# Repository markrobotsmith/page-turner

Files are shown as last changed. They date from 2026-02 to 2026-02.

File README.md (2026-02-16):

# Page Turner

A bluetooth page turning device for musicians. Allows a user to turn pages on a tablet or other bluetooth device. Acts as a bluetooth keyboard and sends left/right arrow key presses.

- **Under $50** in parts
- Simple durable print design with minimal moving parts and assembly. Utilizes compliance as a spring.

## Parts List

- 1× printed enclosure (Polymaker PLA PRO — nearly any material will work)
- 2× keyboard keyswitches (any kind will work; leftover Gateron Yellows were used here) — [Gateron KS-3 Milky Pro](https://www.gateron.co/products/gateron-ks-3-milky-pro-switch-set?variant=41926847463513)
- 1× lithium polymer battery 3.3V 1400mAh — [Amazon](https://www.amazon.com/dp/B095W4HS75) (JST will be removed; polarity does not matter)
- 1× Seeed Studio nRF52840 microcontroller board — [Seeed XIAO BLE nRF52840](https://www.seeedstudio.com/Seeed-XIAO-BLE-nRF52840-p-5201.html)
- 8″×0.5″ adhesive-backed rubber (optional, for feet) — [Amazon](https://www.amazon.com/dp/B0CS2PT17T)

## Assembly

1. Install keyswitches by lifting each pedal and inserting the switch into the hole. Switch should seat so that connectors are accessible from the access compartment.
2. Cut the JST connector off of the battery. **Clip one wire at a time** to prevent shorts.
3. Solder the battery to the pads on the bottom of the nRF52840 board according to the wiring diagram.
4. Insert the nRF52840 and battery. Use hot glue to secure the board from sliding when using the USB-C port. Use a dot of glue behind the battery to secure it.
5. Cut 4 lengths of wire and solder the keyswitches to the inputs of the board according to the wiring diagram.
6. Plug the board into a computer and follow the [board configuration process](https://wiki.seeedstudio.com/XIAO_BLE/) from Seeed Studio, then upload the Arduino sketch.
7. Open Bluetooth settings on your device and pair to **PageTurner** as with any other Bluetooth device.
8. Turn pages hands-free!

## Battery

The nRF52840 has built-in battery charging. Simply charge via the USB-C port. Auto-sleep puts the device into low-power mode to preserve battery life.

## Quick Reference

| Action | How |
|---|-----|
| **Wake** | Press any button |
| **Next page** | Press → button (green flash) |
| **Previous page** | Press ← button (green flash) |
| **Reset pairing** | Hold → for 5 seconds (10 blue blinks = confirmed) |
| **Check battery** | Bluetooth settings on your device |
| **Auto-sleep** | After 30 min inactivity (yellow warning at 25 min) |

### LED Quick Reference

| Color | Pattern | Meaning |
| :---- | :--- | :--- |
| Blue | 2 blinks | Powered on |
| Green | Slow breath | Connected |
| Green | Quick flash | Success |
| Red | Quick flash | Not connected |
| Yellow | 3 blinks | Inactivity warning |
| Red | 3 slow blinks | Going to sleep |
| Blue | 10 rapid blinks | Pairing reset |

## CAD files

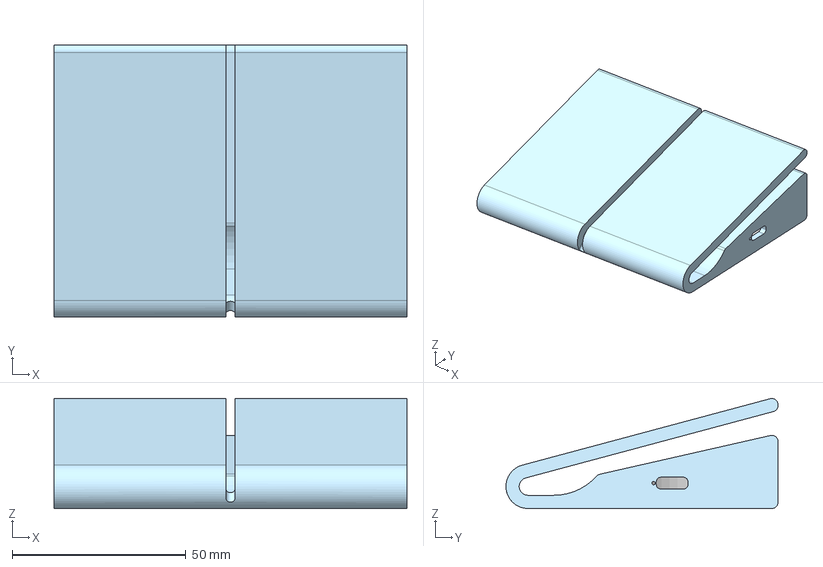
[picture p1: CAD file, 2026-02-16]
Page Turner v3.step
101.6 x 78.3 x 31.7 mm

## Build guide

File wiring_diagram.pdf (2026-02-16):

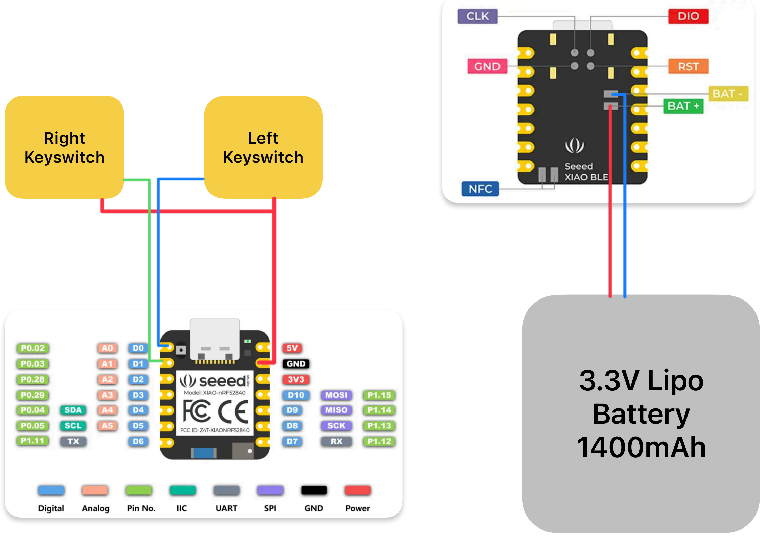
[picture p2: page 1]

# 3.3V Lipo Battery 1400mAh

Right
Keyswitch

Left
Keyswitch

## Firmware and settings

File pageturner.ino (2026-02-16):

#include <bluefruit.h>

// --- Config ---
#define PIN_BTN_NEXT    0  // D0
#define PIN_BTN_PREV    1  // D1

// XIAO nRF52840 specific internal pins for battery
#define PIN_VBAT        32 // P0.31 (AIN7) - Battery voltage sense
#define PIN_VBAT_ENABLE 14 // P0.14 - LOW to enable battery reading
#define PIN_HICHG       22 // P0.17 - Charge current setting (LOW=100mA, HIGH=50mA)
#define PIN_CHG         23 // P0.13 - Charge indicator (LOW=charging, HIGH=not charging)

// Auto-sleep timeout (1/2 hour = 3600000 ms)
#define INACTIVITY_TIMEOUT_MS 1800000UL  // 30min
//#define INACTIVITY_TIMEOUT_MS 60000UL  // 1 minute for testing

// Battery update interval (every 60 seconds)
#define BATTERY_UPDATE_INTERVAL 60000UL

// Warning time before auto-sleep (5 minutes before timeout)
#define WARNING_TIME_BEFORE_SLEEP 300000UL  // 5 minutes

BLEHidAdafruit blehid;
BLEBas blebas; // Battery Service
BLEDis bledis;

// Track last activity time
unsigned long lastActivityTime = 0;
unsigned long lastBatteryUpdate = 0;
bool warningShown = false;

void setup() {
  // 1. Setup Hardware
  pinMode(PIN_BTN_NEXT, INPUT_PULLUP);
  pinMode(PIN_BTN_PREV, INPUT_PULLUP);
  pinMode(LED_RED, OUTPUT);
  pinMode(LED_BLUE, OUTPUT);
  pinMode(LED_GREEN, OUTPUT);
  
  // Turn off all LEDs (active LOW on XIAO)
  digitalWrite(LED_RED, HIGH);
  digitalWrite(LED_BLUE, HIGH);
  digitalWrite(LED_GREEN, HIGH);
  
  // Battery monitoring pins
  pinMode(PIN_VBAT, INPUT);
  pinMode(PIN_VBAT_ENABLE, OUTPUT);
  pinMode(PIN_HICHG, OUTPUT);
  pinMode(PIN_CHG, INPUT);
  
  digitalWrite(PIN_VBAT_ENABLE, LOW);  // Enable battery reading
  digitalWrite(PIN_HICHG, LOW);        // Set charge current to 100mA
  
  // Initialize ADC for battery reading
  analogReference(AR_DEFAULT);    // 0.6V * 6 = 3.6V reference
  analogReadResolution(12);       // 12-bit resolution (0-4095)

  // 2. Setup Bluetooth
  Bluefruit.begin();
  Bluefruit.setTxPower(4); // +4dBm for good range
  Bluefruit.setName("PageTurner");
  
  // CRITICAL: Disable connection LED to prevent advertising issues
  Bluefruit.setConnLedInterval(0);
  
  bledis.setManufacturer("markrobotsmith");
  bledis.setModel("ptv1");
  bledis.begin();

  // Security setup for pairing
  Bluefruit.Security.setMITM(false);
  Bluefruit.Security.setIOCaps(false, false, false);
  
  // 3. Setup Services
  blebas.begin(); // Battery service
  blehid.begin();

  // 4. Advertising Packet (Keep it minimal to avoid overflow)
  Bluefruit.Advertising.addFlags(BLE_GAP_ADV_FLAGS_LE_ONLY_GENERAL_DISC_MODE);
  Bluefruit.Advertising.addTxPower();
  Bluefruit.Advertising.addAppearance(BLE_APPEARANCE_HID_KEYBOARD);
  Bluefruit.Advertising.addService(blehid);
  
  // 5. Scan Response (Put additional services here to avoid packet overflow)
  Bluefruit.ScanResponse.addName();
  Bluefruit.ScanResponse.addService(blebas); // Battery service in scan response
  
  // 6. Start Advertising
  Bluefruit.Advertising.restartOnDisconnect(true);
  Bluefruit.Advertising.setInterval(32, 244); // Fast/Slow adv intervals in 0.625ms units
  Bluefruit.Advertising.setFastTimeout(30);   // Fast adv for 30s
  Bluefruit.Advertising.start(0);             // 0 = Don't stop advertising
  
  // === STARTUP FEEDBACK ===
  // Double blue blink: Device is powered on and advertising
  blinkLED(LED_BLUE, 2, 200);
  
  // 7. Setup Deep Sleep Wakeup Pins
  nrf_gpio_cfg_sense_input(g_ADigitalPinMap[PIN_BTN_NEXT], NRF_GPIO_PIN_PULLUP, NRF_GPIO_PIN_SENSE_LOW);
  nrf_gpio_cfg_sense_input(g_ADigitalPinMap[PIN_BTN_PREV], NRF_GPIO_PIN_PULLUP, NRF_GPIO_PIN_SENSE_LOW);
  
  // Initialize activity timer
  lastActivityTime = millis();
  lastBatteryUpdate = millis();
  
  // Initial battery reading
  updateBattery();
}

void loop() {
  // === PERIODIC BATTERY UPDATE ===
  // Update battery level every 60 seconds when connected
  if (Bluefruit.connected() && (millis() - lastBatteryUpdate >= BATTERY_UPDATE_INTERVAL)) {
    updateBattery();
    lastBatteryUpdate = millis();
  }
  
  // === CONNECTION STATUS INDICATOR ===
  // Slow breathing green when connected (every 3 seconds)
  static unsigned long lastBreathTime = 0;
  if (Bluefruit.connected() && (millis() - lastBreathTime > 3000)) {
    breathLED(LED_GREEN, 100);
    lastBreathTime = millis();
  }
  
  // === PAIRING RESET LOGIC ===
  if (digitalRead(PIN_BTN_NEXT) == LOW) {
    unsigned long startPress = millis();
    while (digitalRead(PIN_BTN_NEXT) == LOW) {
      // Hold indicator - blink blue faster as you hold longer
      if (millis() - startPress > 5000) {
        // 5 Seconds passed: PAIRING RESET
        // Rapid blue flashes to confirm reset
        blinkLED(LED_BLUE, 10, 50);
        Bluefruit.Central.clearBonds(); // Forget all phones
        Bluefruit.Advertising.restartOnDisconnect(true); 
        return;
      } else if (millis() - startPress > 3000) {
        // Warning: getting close to reset
        pulseLED(LED_BLUE, 1);
      }
    }
    
    // === BUTTON PRESS FEEDBACK ===
    if (Bluefruit.connected()) {
      // Send key command
      uint8_t keycodesLeft[6] = { HID_KEY_ARROW_RIGHT, HID_KEY_NONE , HID_KEY_NONE , HID_KEY_NONE , HID_KEY_NONE , HID_KEY_NONE };
      blehid.keyboardReport(0, keycodesLeft);
      blehid.keyRelease();
      
      // Quick green flash: Key sent successfully
      flashQuick(LED_GREEN);
      
      // Reset inactivity timer and warning flag
      lastActivityTime = millis();
      warningShown = false;
    } else {
      // Not connected - quick red flash
      flashQuick(LED_RED);
    }
    
    delay(200); // Debounce
  }

  if (digitalRead(PIN_BTN_PREV) == LOW) {
    if (Bluefruit.connected()) {
      // Send key command
      uint8_t keycodesRight[6] = { HID_KEY_ARROW_LEFT, HID_KEY_NONE , HID_KEY_NONE , HID_KEY_NONE , HID_KEY_NONE , HID_KEY_NONE };
      blehid.keyboardReport(0, keycodesRight);
      blehid.keyRelease();
      
      // Quick green flash: Key sent successfully
      flashQuick(LED_GREEN);
      
      // Reset inactivity timer and warning flag
      lastActivityTime = millis();
      warningShown = false;
    } else {
      // Not connected - quick red flash
      flashQuick(LED_RED);
    }
    
    delay(200); // Debounce
  }

  // === INACTIVITY WARNING ===
  // Warn 5 minutes before auto-sleep
  if (Bluefruit.connected() && !warningShown) {
    unsigned long inactiveTime = millis() - lastActivityTime;
    
    if (inactiveTime >= (INACTIVITY_TIMEOUT_MS - WARNING_TIME_BEFORE_SLEEP)) {
      // Yellow (red + green) warning blink
      blinkYellow(3, 300);
      warningShown = true;
    }
  }

  // === AUTO-SLEEP LOGIC (INACTIVITY) ===
  if (Bluefruit.connected()) {
    unsigned long inactiveTime = millis() - lastActivityTime;
    
    if (inactiveTime >= INACTIVITY_TIMEOUT_MS) {
      // Going to sleep - triple red blink
      blinkLED(LED_RED, 3, 300);
      
      // Disconnect gracefully
      Bluefruit.disconnect(Bluefruit.connHandle());
      delay(500);
      
      // Disable battery reading to save power
      digitalWrite(PIN_VBAT_ENABLE, HIGH);
      
      // Turn off all LEDs
      allLedsOff();
      
      // Enter System OFF
      sd_power_system_off(); 
    }
  }
  
  // === SLEEP LOGIC (NOT CONNECTED) ===
  // If not connected for 60s, go to DEEP SLEEP
  if (!Bluefruit.connected() && millis() > 60000) { 
     // Triple red blink before sleep
     blinkLED(LED_RED, 3, 300);
     
     // Disable battery reading to save power
     digitalWrite(PIN_VBAT_ENABLE, HIGH);
     
     allLedsOff();
     sd_power_system_off(); 
  }
}

// === BATTERY MONITORING ===
void updateBattery() {
  // Read ADC value (12-bit = 0-4095)
  int vbat_raw = analogRead(PIN_VBAT);
  
  // Convert to voltage using XIAO's resistor divider (2.961 ratio) and 3.6V reference
  // Voltage = ADC * (Vref / ADC_max) * Resistor_ratio
  float voltage = vbat_raw * (3.6 / 4095.0) * 2.961;
  
  // Convert voltage to percentage (LiPo: 4.2V = 100%, 3.3V = 0%)
  // Using a more accurate discharge curve
  int percentage;
  
  if (voltage >= 4.2) {
    percentage = 100;
  } else if (voltage >= 4.0) {
    // 4.2V - 4.0V = 100% - 80% (fast drop at top)
    percentage = 80 + (int)((voltage - 4.0) * 100);
  } else if (voltage >= 3.7) {
    // 4.0V - 3.7V = 80% - 40% (linear middle section)
    percentage = 40 + (int)((voltage - 3.7) * 133);
  } else if (voltage >= 3.4) {
    // 3.7V - 3.4V = 40% - 10% (linear)
    percentage = 10 + (int)((voltage - 3.4) * 100);
  } else if (voltage >= 3.3) {
    // 3.4V - 3.3V = 10% - 0% (rapid drop at bottom)
    percentage = (int)((voltage - 3.3) * 100);
  } else {
    percentage = 0;
  }
  
  // Clamp to valid range
  if (percentage < 0) percentage = 0;
  if (percentage > 100) percentage = 100;
  
  // Update BLE Battery Service
  blebas.write(percentage);
  
  // Optional: Check if charging
  // bool isCharging = (digitalRead(PIN_CHG) == LOW);
}

// === LED HELPER FUNCTIONS ===

// Quick flash (50ms) - for button feedback
void flashQuick(uint8_t pin) {
  digitalWrite(pin, LOW);
  delay(50);
  digitalWrite(pin, HIGH);
}

// Standard blink
void blinkLED(uint8_t pin, int count, int delayMs) {
  for(int i=0; i<count; i++) {
    digitalWrite(pin, LOW);
    delay(delayMs);
    digitalWrite(pin, HIGH);
    delay(delayMs);
  }
}

// Breathing effect (slow fade in/out)
void breathLED(uint8_t pin, int duration) {
  digitalWrite(pin, LOW);
  delay(duration);
  digitalWrite(pin, HIGH);
}

// Pulse effect (quick on/off)
void pulseLED(uint8_t pin, int count) {
  for(int i=0; i<count; i++) {
    digitalWrite(pin, LOW);
    delay(100);
    digitalWrite(pin, HIGH);
    delay(100);
  }
}

// Yellow warning (both red and green)
void blinkYellow(int count, int delayMs) {
  for(int i=0; i<count; i++) {
    digitalWrite(LED_RED, LOW);
    digitalWrite(LED_GREEN, LOW);
    delay(delayMs);
    digitalWrite(LED_RED, HIGH);
    digitalWrite(LED_GREEN, HIGH);
    delay(delayMs);
  }
}

// Turn off all LEDs
void allLedsOff() {
  digitalWrite(LED_RED, HIGH);
  digitalWrite(LED_BLUE, HIGH);
  digitalWrite(LED_GREEN, HIGH);
}
